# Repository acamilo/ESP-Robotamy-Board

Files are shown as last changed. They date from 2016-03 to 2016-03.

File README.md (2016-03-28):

## ESP8266 Robotics Board ##

The ESP-Robotics-Board is an arduino compatible board intended for building robots out of old toys as well as many other simple robotics projects.

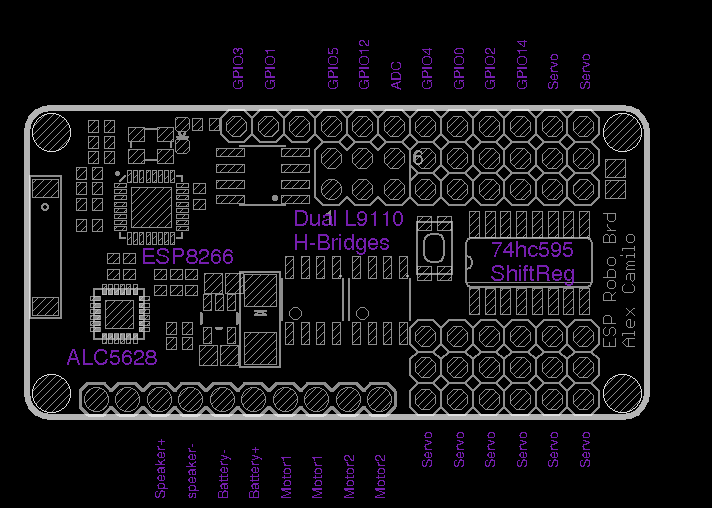
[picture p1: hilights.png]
hilights

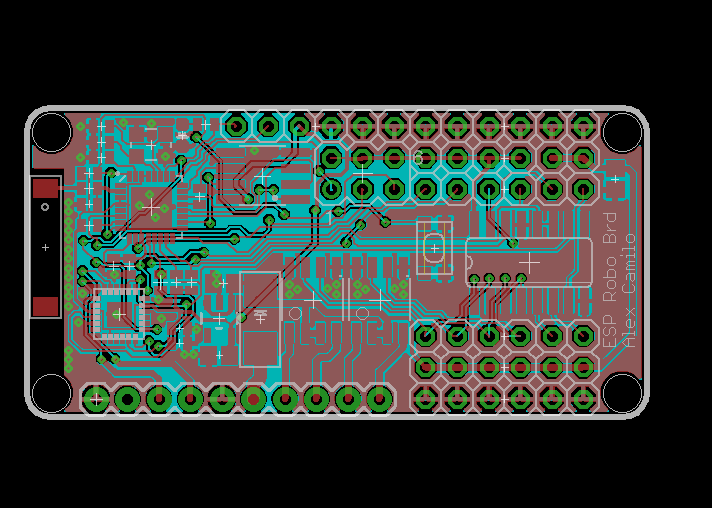
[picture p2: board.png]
board

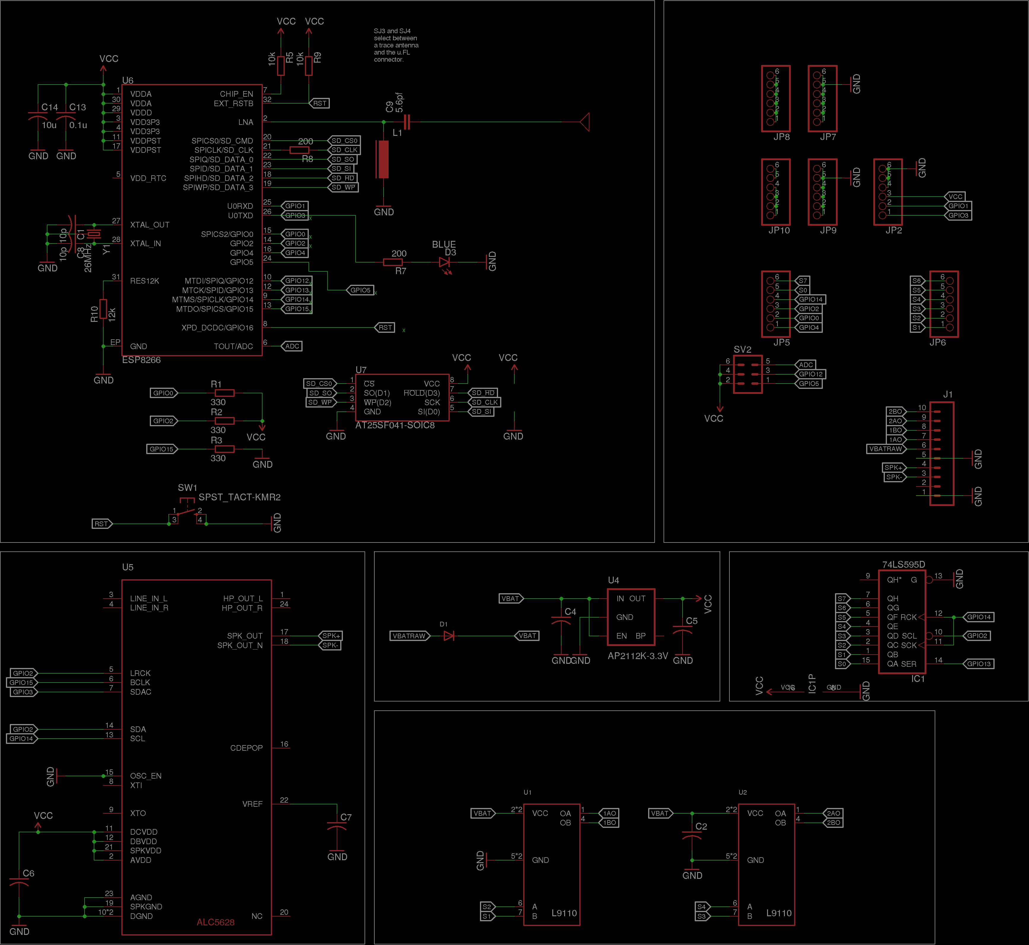
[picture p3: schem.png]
schematic


- ESP8266-12 wifi module
- Dual L9110 (800ma) H-Bridge ICs
 - For small DC motors.
- ALC5628 DAC+AMP
 - Drive an 8 0hm speaker
- Screw Terminals to attatch motors, bettery, speakers
 - Strip wires in up-cycled toys and attatch directly to the board.
- Drive up to 8 servoes
 - 1 motor, 6 servoes
 - 2 motors, 4 servoes
 - 8 GPIO for sensors
  -i2c broken out
  -ADC broken out

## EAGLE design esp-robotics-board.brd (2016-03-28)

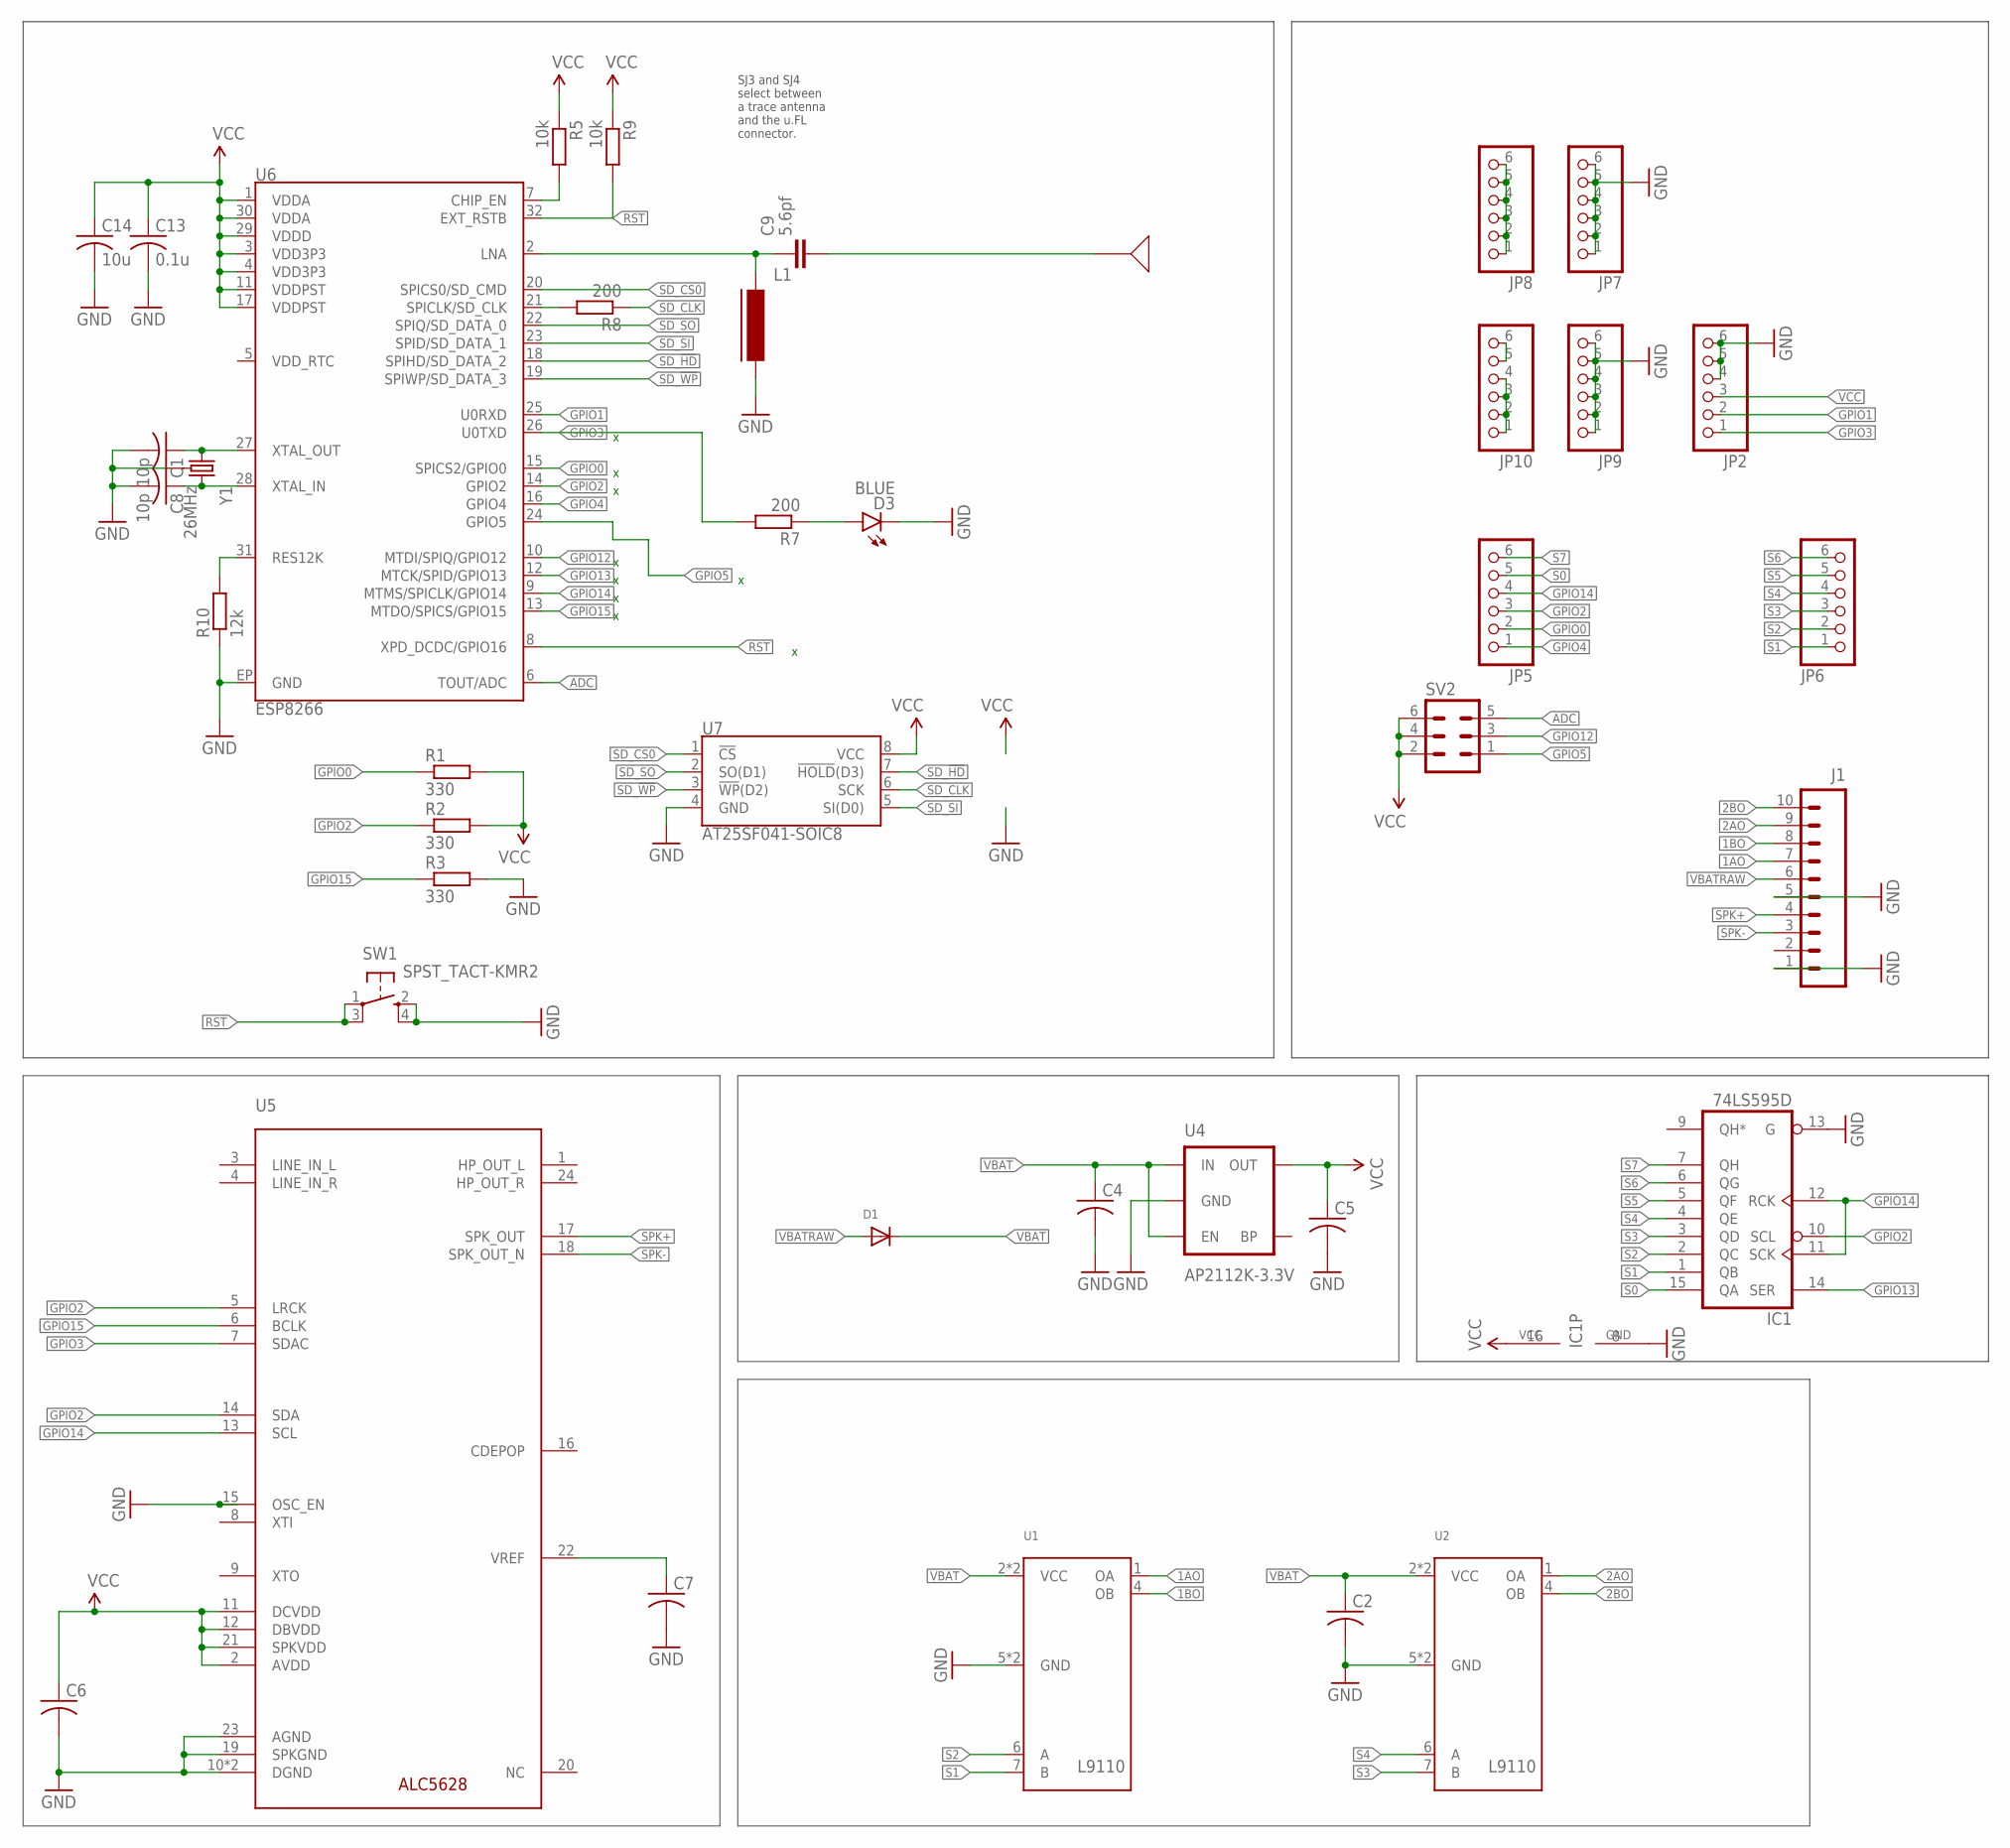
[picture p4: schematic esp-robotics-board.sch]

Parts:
C1, C8: 10p; C0402
C2, C4, C5: C-USC0805; C0805
C6, C7: C-USC0402; C0402
C9: 5.6pf; C402
C13: 0.1u; C0402
C14: 10u; C0402
D1: DIODESMA; SMADIODE
D3: BLUE; LED-0603
IC1: 74LS595D; SO16
J1: M10SILK_FEMALE_PTH; 1X10
JP2, JP5, JP6, JP7, JP8, JP9, JP10: PINHD-1X6; 1X06
L1: FERRITE-0402; FB402
R1, R2, R3: 330; R0402
R5, R9: 10k; R0402
R7, R8: 200; R0402
R10: 12k; R0402
SV2: MA03-2
SW1: SPST_TACT-KMR2; KMR2
U1, U2: L9110SMT; 8S1
U4: AP2112K-3.3V; SOT23-5
U5: ALC5628; QFN24
U6: ESP8266; QFN32
U7: AT25SF041-SOIC8; SO08
U$1: AN9520
Y1: 26MHz; CRYSTAL-SMD-3.2X2.5

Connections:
1AO: J1.7, U1.1 (OA)
1BO: J1.8, U1.4 (OB)
2AO: J1.9, U2.1 (OA)
2BO: J1.10, U2.4 (OB)
ADC: SV2.5, U6.6 (TOUT/ADC)
CHIP_EN: R5.2, U6.7 (CHIP_EN)
GND: C1.2, C2.2, C4.2, C5.2, C6.2, C7.2, C8.2, C13.2, C14.2, D3.C, IC1.8 (GND), IC1.13 (G), J1.1, J1.5, JP2.4, JP2.5, JP2.6, JP7.1, JP7.2, JP7.3, JP7.4, JP7.5, JP7.6, JP9.1, JP9.2, JP9.3, JP9.4, JP9.5, JP9.6, L1.2, R3.2, R10.1, SW1.2 (S), SW1.4 (S1), U1.5 (GND), U1.8 (GND), U2.5 (GND), U2.8 (GND), U4.2 (GND), U5.10 (DGND), U5.19 (SPKGND), U5.23 (AGND), U5.PAD (DGND), U6.EP (GND), U7.4 (GND), Y1.2 (GND), Y1.4 (GND)
GPIO0: JP5.2, R1.1, U6.15 (SPICS2/GPIO0)
GPIO1: JP2.2, U6.25 (U0RXD)
GPIO2: IC1.10 (SCL), JP5.3, R2.1, U5.5 (LRCK), U5.14 (SDA), U6.14 (GPIO2)
GPIO3: JP2.1, R7.2, U5.7 (SDAC), U6.26 (U0TXD)
GPIO4: JP5.1, U6.16 (GPIO4)
GPIO5: SV2.1, U6.24 (GPIO5)
GPIO12: SV2.3, U6.10 (MTDI/SPIQ/GPIO12)
GPIO13: IC1.14 (SER), U6.12 (MTCK/SPID/GPIO13)
GPIO14: IC1.11 (SCK), IC1.12 (RCK), JP5.4, U5.13 (SCL), U6.9 (MTMS/SPICLK/GPIO14)
GPIO15: R3.1, U5.6 (BCLK), U6.13 (MTDO/SPICS/GPIO15)
LNA: C9.1, L1.1, U6.2 (LNA)
LNA2: C9.2, U$1.FEED
unnamed: D3.A, R7.1
unnamed: C7.1, U5.22 (VREF)
unnamed: R10.2, U6.31 (RES12K)
unnamed: C8.1, U6.28 (XTAL_IN), Y1.3 (2)
unnamed: C1.1, U6.27 (XTAL_OUT), Y1.1
RST: R9.2, SW1.1, SW1.3 (P1), U6.8 (XPD_DCDC/GPIO16), U6.32 (EXT_RSTB)
S0: IC1.15 (QA), JP5.5
S1: IC1.1 (QB), JP6.1, U1.7 (B)
S2: IC1.2 (QC), JP6.2, U1.6 (A)
S3: IC1.3 (QD), JP6.3, U2.7 (B)
S4: IC1.4 (QE), JP6.4, U2.6 (A)
S5: IC1.5 (QF), JP6.5
S6: IC1.6 (QG), JP6.6
S7: IC1.7 (QH), JP5.6
SD_!HD!: U6.18 (SPIHD/SD_DATA_2), U7.7 (!HOLD!(D3))
SD_!WP!: U6.19 (SPIWP/SD_DATA_3), U7.3 (!WP!(D2))
SD_CLK: R8.1, U7.6 (SCK)
SD_CLK0: R8.2, U6.21 (SPICLK/SD_CLK)
SD_CS0: U6.20 (SPICS0/SD_CMD), U7.1 (!CS!)
SD_SI: U6.23 (SPID/SD_DATA_1), U7.5 (SI(D0))
SD_SO: U6.22 (SPIQ/SD_DATA_0), U7.2 (SO(D1))
SPK+: J1.4, U5.17 (SPK_OUT)
SPK-: J1.3, U5.18 (SPK_OUT_N)
VBAT: C2.1, C4.1, D1.C, JP8.1, JP8.2, JP8.3, JP8.4, JP8.5, JP8.6, JP10.5, JP10.6, U1.2 (VCC), U1.3 (VCC), U2.2 (VCC), U2.3 (VCC), U4.1 (IN), U4.3 (EN)
VBATRAW: D1.A, J1.6
VCC: C5.1, C6.1, C13.1, C14.1, IC1.16 (VCC), JP2.3, JP10.1, JP10.2, JP10.3, JP10.4, R1.2, R2.2, R5.1, R9.1, SV2.2, SV2.4, SV2.6, U4.5 (OUT), U5.2 (AVDD), U5.11 (DCVDD), U5.12 (DBVDD), U5.21 (SPKVDD), U6.1 (VDDA), U6.3 (VDD3P3), U6.4 (VDD3P3), U6.11 (VDDPST), U6.17 (VDDPST), U6.29 (VDDD), U6.30 (VDDA), U7.8 (VCC)

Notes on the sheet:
SJ3 and SJ4 select between a trace antenna and the u.FL connector.

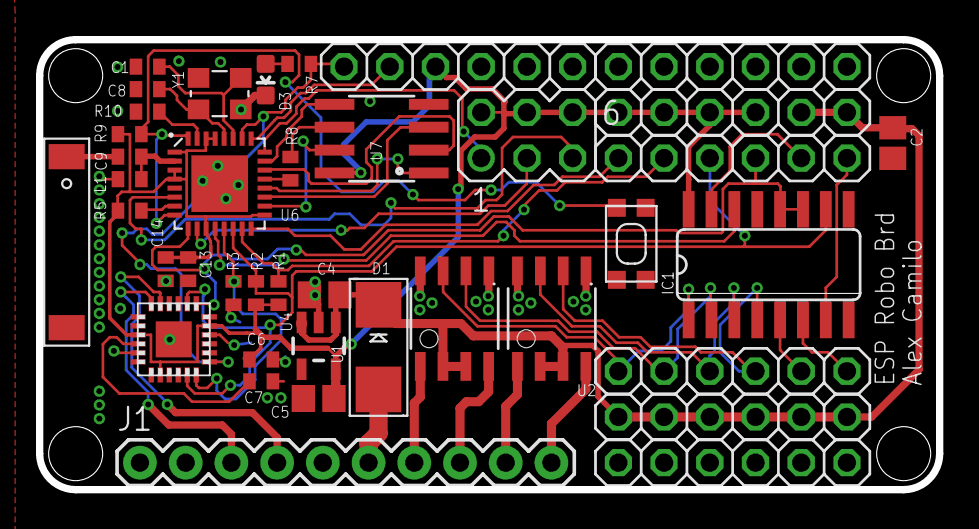
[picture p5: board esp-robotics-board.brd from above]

Board: 2 copper layers, 50.0 x 25.0 mm, 40 parts (0 on the bottom side), 45 nets.

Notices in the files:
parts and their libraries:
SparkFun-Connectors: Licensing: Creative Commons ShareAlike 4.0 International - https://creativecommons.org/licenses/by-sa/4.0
